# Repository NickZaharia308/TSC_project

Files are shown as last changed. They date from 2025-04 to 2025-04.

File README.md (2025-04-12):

# Nicusor-Alexandru Zaharia 335CA – Open-Source E-Book Reader

## Description
**OpenBook** is a fully open-source, ESP32-C6-powered e-book reader designed to be affordable, customizable, and easy to manufacture. It features a crisp e-paper display, modular hardware, and full documentation – empowering developers and hardware enthusiasts to build their own e-reader from scratch.

The project contains the **Product Design** with a complete [`schematic`](Hardware/Schematic.sch), [`PCB`](Hardware/PCB_2D.brd) and [`3D Model`](Mechanical/Completed%203D%20model%20v1.f3z).

---

## Repository Hierarchy

- Hardware
  ├── Schematic file (.sch)  
  └── Board layout file (.brd)  

- Manufacturing
  ├── Gerber files archive (gerbers.zip)  
  ├── Bill of Materials file (.bom)  
  └── Pick and Place file (.cpl)  

- Mechanical
  ├── 3D model of the complete device (PCB + battery + display + case) – exploded view (.step)  
  └── Fusion 360 project file of the complete device  

- Images
  └── Renders of the device

- LICENSE  
- README.md  

---

##  E-Book Reader Block Diagram
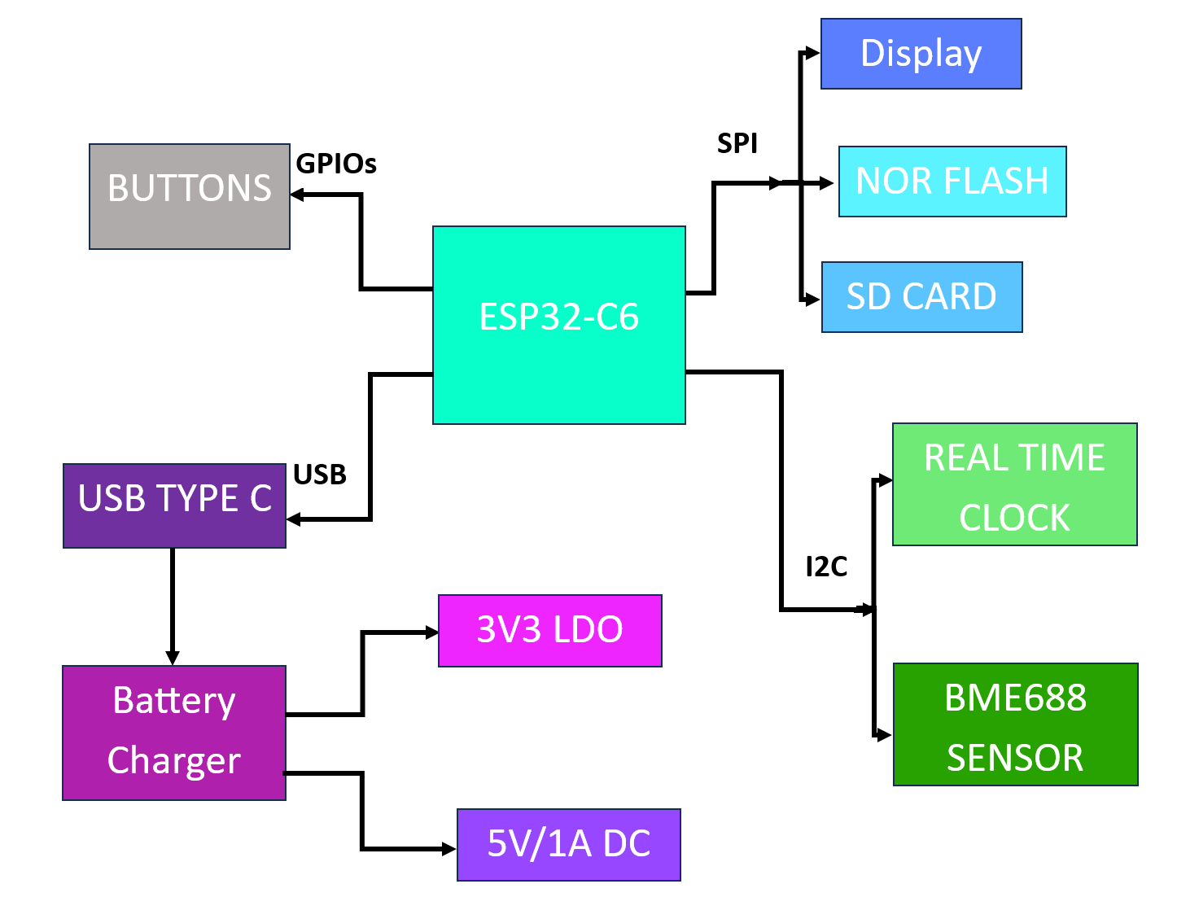
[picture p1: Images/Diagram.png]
E-book diagram


---

##   Design Process

1.  **Schematic Design:** The schematic was meticulously designed to align with the project's specified requirements. It highlights the important `components and modules`.
    
2.  **PCB Redesign:** The PCB layout was generated based on the size of the enclosure, and `components were strategically placed` according to design guidelines and best practices.
    
3.  **Routing Implementation:** Routing was used on both the top and bottom layers of the PCB. `Signal traces` were set to a width of 0.15mm while `the power traces` were organized into a dedicated net class named `Power class` routed with a width of 0.3mm to ensure optimal power distribution.
    
4.  **Ground Plane and Via Stitching:** `Ground planes` were implemented on both the top and bottom layers. `Via stitching` was applied, particularly in proximity to the ESP module, to establish effective interlayer connections and minimize ground impedance. `Vias` were used to interconnect the ground planes.
    
5.  **3D Model Integration:** `3D models` of the components were found with the link to them at the bottom of the README, integrated into Fusion 360, and accurately placed on the `PCB layout` to facilitate mechanical design and visualization.
    
6.  **Enclosure Integration:** The PCB was integrated into its intended enclosure. The enclosure design was adapted to accommodate buttons, connectors, and other external interface elements. `Battery` and `display` 3D models were developed positioned within the enclosure to ensure proper fit and alignment.

7.  **Export and Manufacturing Preparation:** The final stage involved `generating all necessary manufacturing` documentation, including Gerber files, Pick and Place (CPL) data, and the Bill of Materials (BOM), to prepare the design for fabrication and assembly.

---

## Decision Making

I switched the original [battery](https://www.tme.eu/Document/e0683d8c34e6d878124489f71bffb6ee/cel0014.pdf) from cellevia batteries with a similar [one](https://www.elektronik.ropla.eu/pdf/stock/aky/aky0099.pdf) (same electrical parameters) from akyga with a size that enters well in the enclosure and beside that it also has a lifecycle of `500 charges` as opossed to only `300 charges`

---

## Component Description and Interaction

### Microcontroller

* **ESP32-C6-WROOM-1-NI (U2):** This is the core of the board, a powerful microcontroller with Wi-Fi and Bluetooth Low Energy (BLE) connectivity. It is responsible for controlling all other components, processing data, and external communication.

### Power Supply

* **Li-Po Battery Charging Controller (MCP73831):** This circuit enables the board to be powered from a Li-Po battery and manages the charging process when an external power source is connected via the USB-C connector.
* **USB C connector:** Provides the interface for powering the board and potentially for data transfer. Includes `ESD (Electrostatic Discharge) protection`.
* **LDO Voltage Regulator (XC8220A331MR-G):** An LDO (Low Dropout) voltage regulator is used to provide a `stable 3.3V voltage` required for powering most of the components on the board, derived from the battery voltage or USB.
* **Supercapacitor (CPH3225A):** A supercapacitor is present, possibly to provide a backup power source for certain critical functions, such as the RTC module, in case the main power supply is interrupted.
* **Reverse Polarity Protection (MBR0530):** Schottky diodes are used to protect the circuits against incorrect polarity connection of the power source.
* **Capacitors (electrolytic, tantalum, ceramic):** Various types and values of capacitors are used for `power supply filtering, decoupling, and temporary energy storage` at different points in the circuit.

### Display

* **E-Paper Display Header (FH34SR-24S-0.5SH):** A header connector is provided for connecting an `E-Paper display`. This type of display is known for its low power consumption and image retention without power.
* **Display Type Selector:** A set of pull-up/pull-down resistors connected to ESP32-C6 pins allows for the detection of the connected E-Paper display type.

### Sensors

* **Environmental Sensor BME688:** This sensor integrates `temperature, humidity, atmospheric pressure, and air quality` (VOC - volatile organic compounds) measurement functions. It communicates with the ESP32-C6 via the `I2C` interface.
* **RTC Module DS3231SN:** A Real-Time Clock (RTC) module that maintains accurate time and date information, even when the board is powered off, being powered by the supercapacitor or a small battery. It communicates with the ESP32-C6 via `the I2C interface`.
* **Battery Charge Level (MAX17048G+T10):** A dedicated integrated circuit for monitoring the charge level of the Li-Po battery. It communicates with the ESP32-C6 via the `I2C interface`.

### User Interaction

* **Boot/IO Button (BOOT BUTTON):** A button used to force the ESP32-C6 into bootloader mode for programming or to perform an application-specific function.
* **Reset Button (RESET BUTTON):** A button to reset the ESP32-C6 microcontroller.
* **Change Button (CHANGE):** A button with an application-defined functionality, for navigation or selection.
* **CHG LED:** An LED indicator for the battery charging status.

### External Memory

* **External NOR Flash 64MB (W25Q512JVEIQ):** An external `64MB SPI flash memory`, used for storing firmware, data, or additional resources required by the application, exceeding the ESP32-C6's internal flash memory capacity. Good to keep `more books to read`.

### Connectivity and Interfaces

* **USB C connector:** For power and potential data transfer.
* **E-Paper Display Header:** Dedicated connector for the E-Paper display.
* **Qwiic/Stemma QT Connector:** A standard `I2C connector that allows for easy connection of additional I2C-compatible sensors or actuators`.
* **SPI ESD Protection Lines:** ESD protection circuits for the SPI communication lines, used for the external flash memory interface.
* **Test Pads (TP1-TP17):** Test points distributed across the board to facilitate debugging and `signal verification`.

### Miscellaneous

* **GND:** Multiple ground points for ensuring a stable voltage reference.
* **Resistors:** Various resistors are used for `pull-up, pull-down, current limiting, and voltage division`.
* **Diodes:** Diodes with various purposes, such as `protection or rectification`.
* **Inductor:** An inductor, part of the `power supply circuit or for EMI filtering`.
* **MOSFETs:** MOSFET transistors used for power switching or other control functions.

##   ESP32-C6 Pin Usage

The following list details the ESP32-C6 pins used and the reason for their use:

* **Pin 10 (3V3):** Power supply pin for the ESP32-C6, connected to the 3.3V rail generated by the LDO.
* **Pin 8 (GHD):** A ground (GND) pin.
* **Pin 5 (GHD):** A ground (GND) pin.
* **Pin 20 (EN):** Enable pin for the ESP32-C6, controlled by a power management circuit or connected to a pull-up to keep it active.
* **Pin 21 (1011):** Connected to the BOOT button. It is configured as an input and used to initiate the ESP32-C6's bootloader mode at startup or reset. A pull-up resistor (R BOOT 10K) ensures a default high logic level, and pressing the button connects it to GND.
* **Pin 22 (1013):** Connected to the RESET button. Similar to the BOOT button, it's an input used to reset the microcontroller.
* **Pin 23 (1013):** Connected to the CHANGE button. It is configured as an input and used to detect user action. A pull-up resistor (10K) ensures a default high logic level, and pressing the button connects it to GND.
* **Pin 19 (102):** Connected to the SDA (Serial Data) line of the I2C bus. This line is used for bidirectional data communication with the BME688 sensor, the DS3231SN RTC module, and the MAX17048G battery monitoring circuit. Pull-up resistors will be present on the I2C bus.
* **Pin 18 (1015):** Connected to the SCL (Serial Clock) line of the I2C bus. This line provides the synchronization clock signal for I2C communication with the peripherals mentioned above. Similar to SDA, it requires pull-up resistors.
* **Pin 17 (132):** Connected to the CE (Chip Enable) pin of the external flash memory W25Q512JVEIQ. This pin is used to select the flash memory chip for SPI communication.
* **Pin 16 (10220):** Connected to the HOLD/RESET pin of the external flash memory. This pin has multiple functions related to controlling the write and read operations of the flash memory.
* **Pin 15 (10):** Connected to the WP (Write Protect) pin of the external flash memory. This pin is used to protect certain sectors of the flash memory against accidental writing.
* **Pin 14 (CE BAT):** Connected to the CE (Chip Enable) pin of the MAX17048G battery monitoring circuit. Used to enable communication with this circuit on the I2C bus.

**Pins Connected to E-Paper Display Header (FH34SR-24S-0.5SH):**

Several ESP32-C6 pins will be connected to the E-Paper display header to control and transmit data to it.

* Powering the display (via "EPD Power").
* Transmitting the data and control signals necessary for updating the image on the display. This could include pins for an SPI interface (data, clock, chip select) or another interface specific to the E-Paper display controller.

**Pins Connected to BME688 Sensor:**

* **SDA (connected to Pin 19 of ESP32-C6):** I2C data line.
* **SCL (connected to Pin 18 of ESP32-C6):** I2C clock line.
* **VDDIO:** Power supply pin for the sensor's logic interface, connected to 3.3V.
* **VDD:** Power supply pin for the sensor, connected to 3.3V.
* **CSH:** Chip Select pin for the SPI interface.
* **SCK:** Serial Clock pin for the SPI interface.
* **SDO:** Serial Data Out pin for the SPI interface.

**Pins Connected to DS3231SN RTC Module:**

* **SDA (connected to Pin 19 of ESP32-C6):** I2C data line.
* **SCL (connected to Pin 18 of ESP32-C6):** I2C clock line.
* **VCC:** Power supply pin, connected to 3.3V or the supercapacitor voltage to maintain RTC operation.
* **SQW/INT# (ALERT):** An output pin that can be configured as a square wave output or an alarm/interrupt output, connected to a GPIO pin of the ESP32-C6.

**Pins Connected to MAX17048G Battery Charge Level Circuit:**

* **SDA (connected to Pin 19 of ESP32-C6):** I2C data line.
* **SCL (connected to Pin 18 of ESP32-C6):** I2C clock line.
* **CE (connected to Pin 14 of ESP32-C6):** Chip Enable pin for selecting the I2C circuit.
* **ALERT:** An alert output pin that can indicate low battery level or other events, connected to a GPIO pin of the ESP32-C6.

**Pins Connected to W25Q512JVEIQ (U1) External Flash Memory:**

* **CS# (Chip Select):** Connected to Pin 17 of ESP32-C6.
* **CLK (Serial Clock):** An ESP32-C6 SPI CLK pin.
* **MOSI (Master Out Slave In):** An ESP32-C6 SPI MOSI pin.
* **MISO (Master In Slave Out):** An ESP32-C6 SPI MISO pin.
* **HOLD/RESET#:** Connected to Pin 16 of ESP32-C6.
* **WP# (Write Protect):** Connected to Pin 15 of ESP32-C6.

**Pins Connected to Qwiic/Stemma QT Connector:**

* **SDA:** Connected to Pin 19 of ESP32-C6.
* **SCL:** Connected to Pin 18 of ESP32-C6.
* **VCC (3V3):** Power supply for connected devices.
* **GND:** Ground.

---

## Images

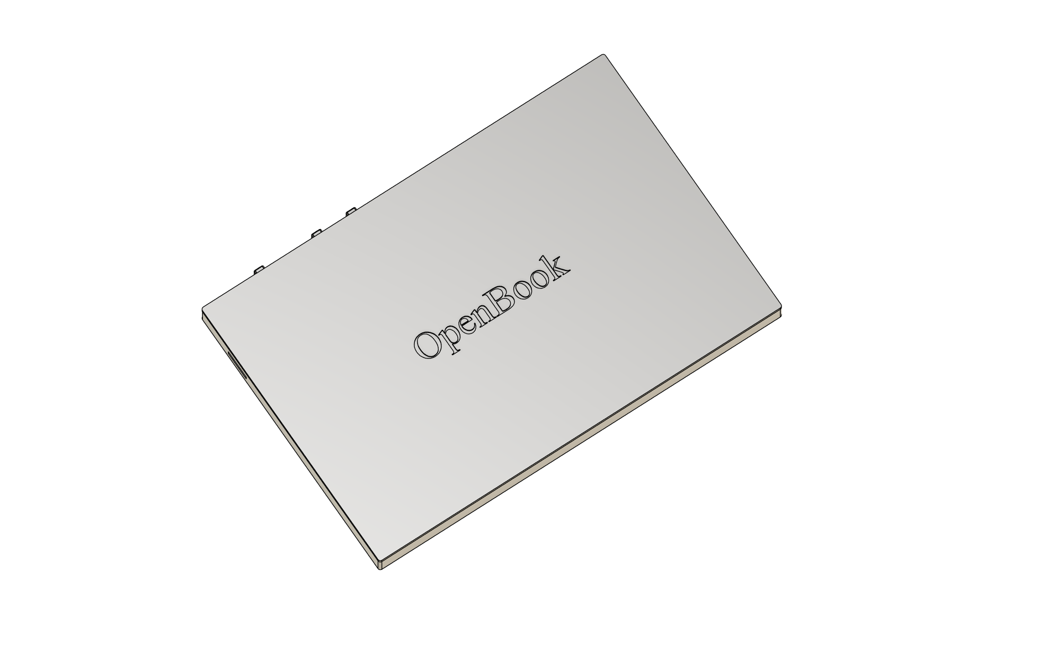
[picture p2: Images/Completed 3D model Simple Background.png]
Product
  
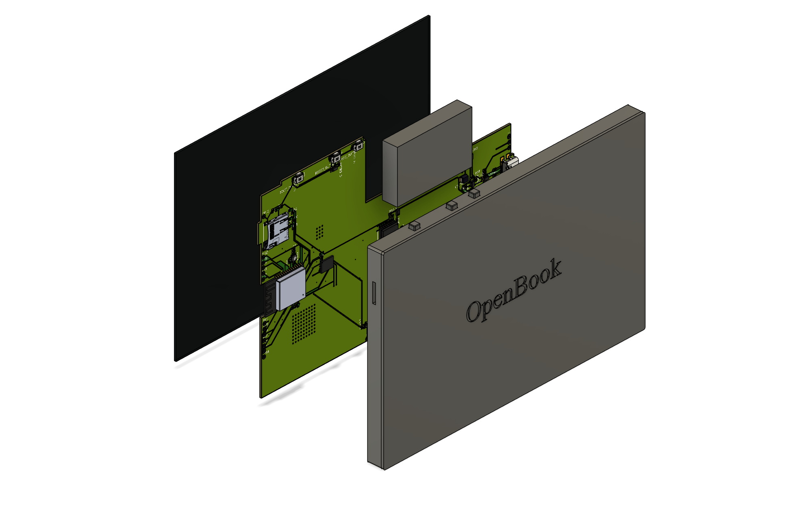
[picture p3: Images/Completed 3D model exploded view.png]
Exploded view

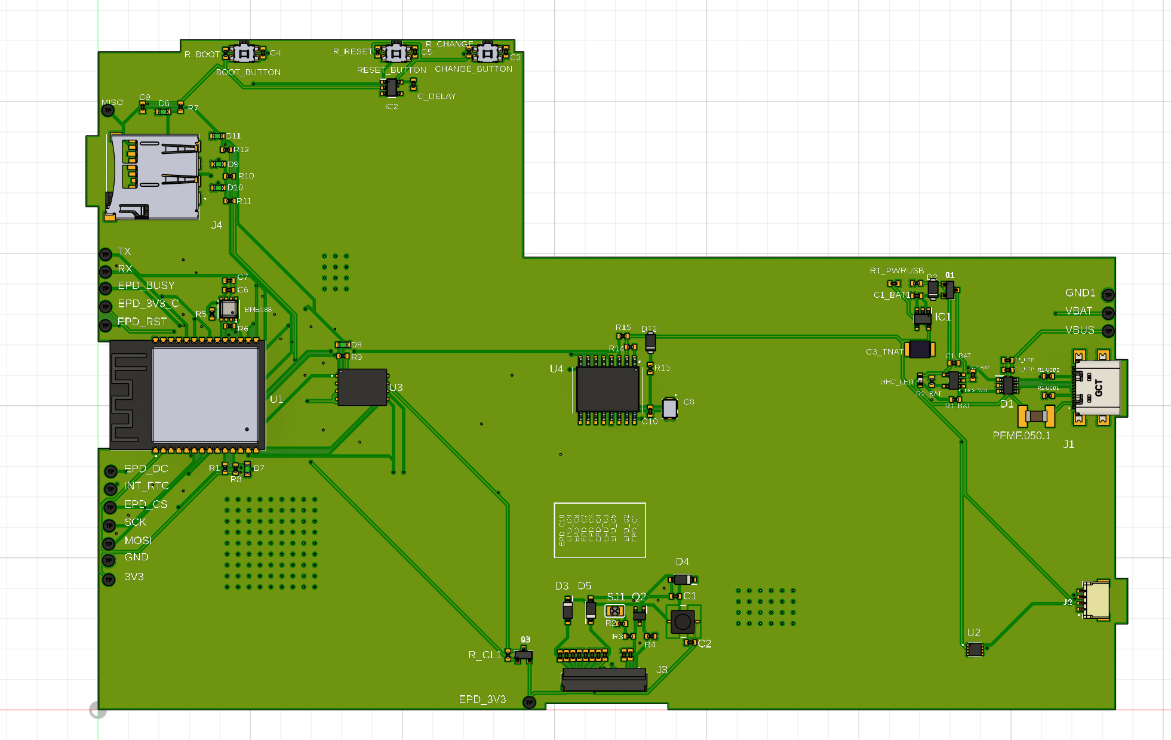
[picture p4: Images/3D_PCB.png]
3D_PCB


---

## Bill of Materials

| Component | Product Link | Datasheet |
|---|---|---|
| ESP32-C6 WROOM-1-N8 | [SnapMagic](https://www.snapeda.com/parts/ESP32-C6-WROOM-1-N8/Espressif+Systems/view-part/?ref=eda) | [Datasheet](https://www.snapeda.com/parts/ESP32-C6-WROOM-1-N8/Espressif%20Systems/datasheet/) |
| ESP32C6 Varistor 1812 | [Mouser](https://ro.mouser.com/ProductDetail/EPCOS-TDK/B72520T0350K062?qs=dEfas%2FXlABIszF52uu7vrg%3D%3D) | [Datasheet](https://www.tdk-electronics.tdk.com/inf/75/db/CTVS_14/Surge_protection_series.pdf) |
| ESP32 WROVER 0805 Capacitor | [Mouser](https://ro.mouser.com/ProductDetail/KYOCERA-AVX/SD0805S020S1R0?qs=jCA%252BPfw4LHbpkAoSnwrdjw%3D%3D) | [Datasheet](https://ro.mouser.com/datasheet/2/40/schottky-3165252.pdf) |
| ESP32 WROVER BME680 Sensor | [SnapMagic](https://www.snapeda.com/parts/BME680/Bosch/view-part/?welcome=home) | [Datasheet](https://www.snapeda.com/parts/BME680/Bosch%20Sensortec/datasheet/) |
| ESP32 WROVER MCP73831 Power Management | [Mouser](https://eu.mouser.com/ProductDetail/Microchip-Technology/MCP73831T-2ACI-OT?qs=yUQqVecv4qvbBQBGbHx0Mw%3D%3D) | [Datasheet](https://eu.mouser.com/datasheet/2/268/MCP73831_Family_Data_Sheet_DS20001984H-3441711.pdf) || ESP32 WROVER P-Channel MOSFET | [Component Search Engine](https://componentsearchengine.com/part-view/DMG2305UX-7/Diodes%20Incorporated) | [Datasheet](https://www.diodes.com//assets/Datasheets/DMG2305UX.pdf) |
| LED Chip 0603 | [SnapMagic](https://www.snapeda.com/parts/KP-1608SURCK/Kingbright/view-part/?ref=search&t=LED%200603) | [Datasheet](https://www.snapeda.com/parts/KP-1608SURCK/Kingbright/datasheet/) |
| SJ | [GrabCad](https://grabcad.com/library/solder-jumpers-1) | [Datasheet](https://en.wikipedia.org/wiki/HTTP_404) |
| LTSPICE Resistor 0402 | [Component Search Engine](https://componentsearchengine.com/part-view/R0402%201%25%20100%20K%20(RC0402FR-07100KL)/YAGEO) | [Datasheet](https://www.yageo.com/upload/media/product/products/datasheet/rchip/PYu-RC_Group_51_RoHS_L_12.pdf) |
| RCL CPOL 3528 | [SnapMagic](https://www.snapeda.com/parts/TAJB475K025RNJ/AVX/view-part/?ref=dk&t=capacitor%203528&con_ref=None) | [Datasheet](https://s3.amazonaws.com/snapeda/datasheet/TAJB475K025RNJ_AVX.pdf) |
| 112A-TAAR-R03 | [Comet](https://store.comet.srl.ro/Catalogue/Product/43497/) | [Datasheet](https://store.comet.bg/download-file.php?id=27596) |
| Capacitor 0402 | [Component Search Engine](https://componentsearchengine.com/part-view/CC0402MRX5R5BB106/YAGEO) | [Datasheet](https://componentsearchengine.com/Datasheets/2/CC0402MRX5R5BB106.pdf) |
| 744043680 IND | [Mouser](https://eu.mouser.com/ProductDetail/Wurth-Elektronik/744043680?qs=PGXP4M47uW6VkZq%252BkzjrHA%3D%3D) | [Datasheet](https://www.we-online.com/components/products/datasheet/744043680.pdf) |
| BD5229G-TR | [Component Search Engine](https://componentsearchengine.com/part-view/BD5229G-TR/ROHM%20Semiconductor) | [Datasheet](https://datasheet.datasheetarchive.com/originals/distributors/Datasheets_SAMA/f2b9741ef86007909f138d561a359946.pdf) |
| Custom Button | [Panasonic](https://industry.panasonic.com/global/en/products/control/switch/light-touch/number/evqpuj02k) | [Datasheet](https://industry.panasonic.com/global/en/downloads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) |
| CPH3225A | [SnapMagic](https://www.snapeda.com/parts/CPH3225A/Seiko+Instruments/view-part/?ref=eda) | [Datasheet](https://www.snapeda.com/parts/CPH3225A/Seiko%20Instruments/datasheet/) |
| DS3231SN RTC | [SnapMagic](https://www.snapeda.com/parts/DS3231SN%23/Analog+Devices/view-part/?ref=eda) | [Datasheet](https://www.snapeda.com/parts/DS3231SN%23/Analog%20Devices/datasheet/) |
| FH34SRJ-24S-0.5SH Connector | [Component Search Engine](https://componentsearchengine.com/part-view/FH34SRJ-24S-0.5SH(99)/Hirose) | [Datasheet](https://www.hirose.com/en/product/document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) |
| MAX17048G+T10 Battery Fuel Gauge | [SnapMagic](https://www.snapeda.com/parts/MAX17048G+T10/Analog+Devices/view-part/?ref=eda) | [Datasheet](https://www.snapeda.com/parts/MAX17048G+T10/Analog%20Devices/datasheet/) |
| MBR0530 Schottky Diode | [SnapMagic](https://www.snapeda.com/parts/MBR0530/Onsemi/view-part/?ref=eda) | [Datasheet](https://www.snapeda.com/parts/MBR0530/ON%20Semiconductor/datasheet/) |
| PGB1010603MR Inductor | [SnapMagic](https://www.snapeda.com/parts/PGB1010603MR/Littelfuse/view-part/?ref=eda) | [Datasheet](https://www.snapeda.com/parts/PGB1010603MR/Littelfuse%20Inc./datasheet/) |
| QWIIC Connector | [Mouser](https://eu.mouser.com/ProductDetail/Adafruit/4208?qs=PzGy0jfpSMtbScLbr0L5dw%3D%3D) | [Datasheet](https://en.wikipedia.org/wiki/HTTP_404) |
| USB4110-GF-A USB Hub | [Component Search Engine](https://componentsearchengine.com/part-view/USB4110-GF-A/GCT%20(GLOBAL%20CONNECTOR%20TECHNOLOGY)) | [Datasheet](https://gct.co/files/drawings/usb4110.pdf) |
| SI1308EDL-T1-GE3 MOSFET | [SnapMagic](https://www.snapeda.com/parts/SI1308EDL-T1-GE3/Vishay+Siliconix/view-part/?ref=eda) | [Datasheet](https://en.wikipedia.org/wiki/HTTP_404) |
| TPTP20R | [Comet](https://easyeda.com/component/7524403feb2642ac9f9f26dfb93ceacf) | [Datasheet](https://easyeda.com/component/7524403feb2642ac9f9f26dfb93ceacf) |
| USBLC6-2SC6Y USB Surge Protection | [SnapMagic](https://www.snapeda.com/parts/USBLC6-2SC6Y/STMicroelectronics/view-part/?ref=eda) | [Datasheet](https://www.snapeda.com/parts/USBLC6-2SC6Y/STMicroelectronics/datasheet/) |
| W25Q512JVEIQ Flash Memory | [SnapMagic](https://www.snapeda.com/parts/W25Q512JVEIQ/Winbond+Electronics/view-part/?ref=eda) | [Datasheet](https://www.snapeda.com/parts/W25Q512JVEIQ/Winbond%20Electronics/datasheet/) |
| XC6220A331MR-G Voltage Regulator | [Component Search Engine](https://componentsearchengine.com/part-view/XC6220A331MR-G/Torex) | [Datasheet](https://product.torexsemi.com/system/files/series/xc6220.pdf) |

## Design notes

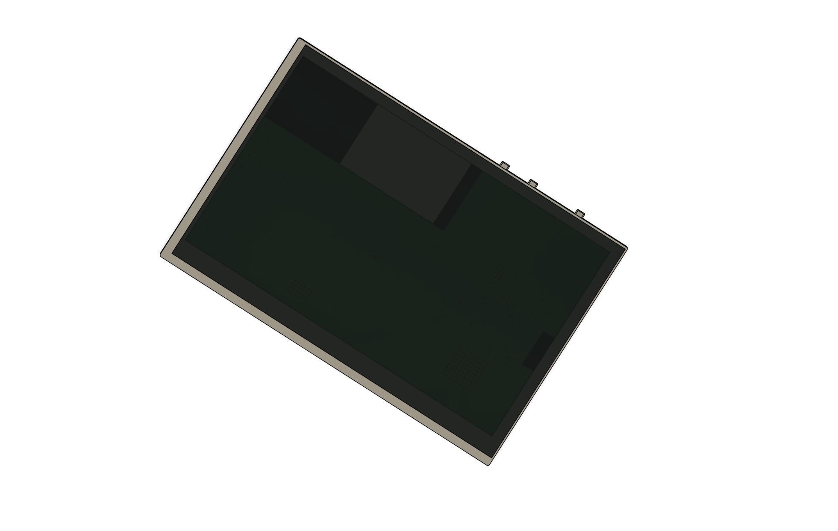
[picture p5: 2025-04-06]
Images/Completed 3D model Transparent Display.png

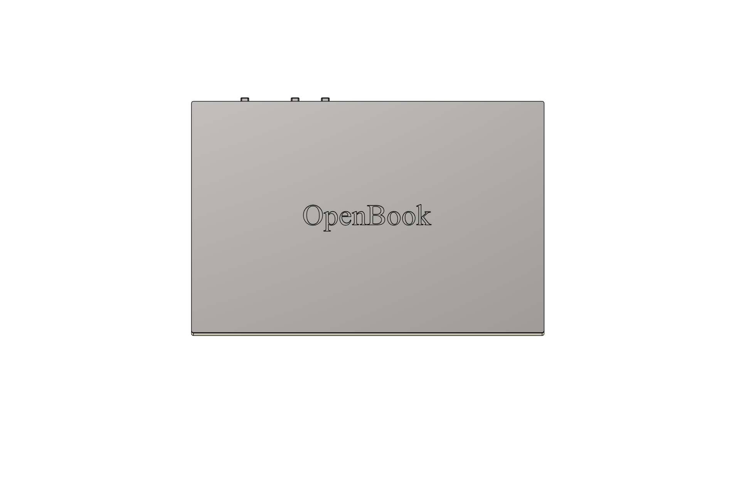
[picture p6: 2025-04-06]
Images/Completed 3D model Top Model.png

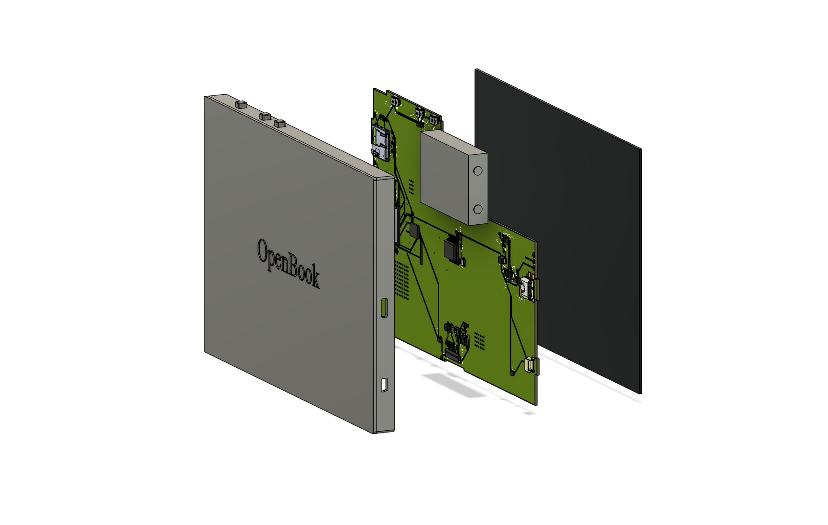
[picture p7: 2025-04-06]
Images/Completed 3D model exploded view 2.png

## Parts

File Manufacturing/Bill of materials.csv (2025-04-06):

Qty | Value | Device | Package | Parts | Description | ARROW_PART_NUMBER | ARROW_PRICE-STOCK | AVAILABILITY | CENTROID_NOT_SPECIFIED | CHECK_PRICES | COPYRIGHT | DATASHEET | DESCRIPTION | DIGIKEY_DESCRIPTION | DIGIKEY_PART_NUMBER | HEIGHT | LEAD_FREE | MANUFACTURER_NAME | MANUFACTURER_PART_NUMBER | MF | MFR_NAME | MOUSER_PART_NUMBER | MOUSER_PRICE-STOCK | MP | MPN | PACKAGE | POPULARITY | PREFIX | PRICE | PROD_ID | PURCHASE-URL | ROHS | SNAPEDA_LINK | SPICEMODEL | SPICEPREFIX | TEMPERATURE_RANGE_HIGH | TEMPERATURE_RANGE_LOW | TP_SIGNAL_NAME | VALUE
1 |  | ADAFRUIT_LEDCHIP-LED0603 | ADAFRUIT_CHIP-LED0603 | GHC_LED | LED
1 |  | SJ | SJ | SJ1 | SMD solder JUMPER |  |  |  |  |  |  |  |  |  |  |  |  |  |  |  |  |  |  |  |  |  | 3
1 | 0.1uF/50V | EAGLE-LTSPICE_CC0402 | EAGLE-LTSPICE_C0402 | EPD_C5 | CAPACITOR, European symbol |  |  |  |  |  |  |  |  |  |  |  |  |  |  |  |  |  |  |  |  |  |  |  |  |  |  |  |  | NONE | C
1 | 0.47 | ESP32_WROVER_EAGLE-LTSPICE_R | ESP32_WROVER_EAGLE-LTSPICE_R0402 | R3 | RESISTOR, European symbol
1 | 100K | ESP32_WROVER_EAGLE-LTSPICE_R | ESP32_WROVER_EAGLE-LTSPICE_R0402 | R1_PWRUSB | RESISTOR, European symbol
8 | 100nF | EAGLE-LTSPICE_CC0402 | EAGLE-LTSPICE_C0402 | C3, C4, C4_USB, C6, C7, C9, C10, C_DELAY | CAPACITOR, European symbol |  |  |  |  |  |  |  |  |  |  |  |  |  |  |  |  |  |  |  |  |  |  |  |  |  |  |  |  | NONE | C
1 | 100uF | RCL_CPOL-EUCT3528 | RCL_CT3528 | C3_TNAT | POLARIZED CAPACITOR, European symbol |  |  |  |  |  |  |  |  |  |  |  |  |  |  |  |  |  |  |  |  |  | 0 |  |  |  |  |  |  |  | C
16 | 10K | ESP32_WROVER_EAGLE-LTSPICE_R | ESP32_WROVER_EAGLE-LTSPICE_R0402 | R1, R4, R5, R6, R7, R8, R9, R10, R11, R12, R14, R15, R_BOOT, R_CHANGE, R_CL1, R_RESET | RESISTOR, European symbol
1 | 10uF | EAGLE-LTSPICE_CC0402 | EAGLE-LTSPICE_C0402 | C2 | CAPACITOR, European symbol |  |  |  |  |  |  |  |  |  |  |  |  |  |  |  |  |  |  |  |  |  |  |  |  |  |  |  |  | NONE | C
1 | 112A-TAAR-R03_ATTENDPACHET | 112A-TAAR-R03_ATTENDPACHET | 112ATAARR03ATTEND | J4 | Micro SD Card Socket, Push-Push Type, Top Mount, SMT, H=1.83mm, 10u
1 | 15 | ESP32_WROVER_EAGLE-LTSPICE_R | ESP32_WROVER_EAGLE-LTSPICE_R0402 | R13 | RESISTOR, European symbol
1 | 1uF | EAGLE-LTSPICE_CC0402 | EAGLE-LTSPICE_C0402 | C5 | CAPACITOR, European symbol |  |  |  |  |  |  |  |  |  |  |  |  |  |  |  |  |  |  |  |  |  |  |  |  |  |  |  |  | NONE | C
9 | 1uF/50V | EAGLE-LTSPICE_CC0402 | EAGLE-LTSPICE_C0402 | EPD_C1, EPD_C2, EPD_C3, EPD_C4, EPD_C6, EPD_C7, EPD_C8, EPD_C9, EPD_C10 | CAPACITOR, European symbol |  |  |  |  |  |  |  |  |  |  |  |  |  |  |  |  |  |  |  |  |  |  |  |  |  |  |  |  | NONE | C
1 | 2.2 | ESP32_WROVER_EAGLE-LTSPICE_R | ESP32_WROVER_EAGLE-LTSPICE_R0402 | R2 | RESISTOR, European symbol
1 | 200 | ESP32_WROVER_EAGLE-LTSPICE_R | ESP32_WROVER_EAGLE-LTSPICE_R0402 | R1_BAT | RESISTOR, European symbol
2 | 20V/4.2A/52mO/1.4W | ESP32_WROVER_SPARKFUN-DISCRETESEMI_MOSFET_PCH-DMG2305UX-7 | ESP32_WROVER_SPARKFUN-DISCRETESEMI_SOT23-3 | Q1, Q3 | P-channel MOSFETs |  |  |  |  |  |  |  |  |  |  |  |  |  |  |  |  |  |  |  |  |  |  |  |  | TRAN-14388 |  |  |  |  |  |  |  |  | 20V/4.2A/52mO/1.4W
1 | 2K | ESP32_WROVER_EAGLE-LTSPICE_R | ESP32_WROVER_EAGLE-LTSPICE_R0402 | R2_BAT | RESISTOR, European symbol
5 | 4.7uF | EAGLE-LTSPICE_CC0402 | EAGLE-LTSPICE_C0402 | C1_BAT, C1_BAT1, C1_BAT2, C2_BAT, C5_USB | CAPACITOR, European symbol |  |  |  |  |  |  |  |  |  |  |  |  |  |  |  |  |  |  |  |  |  |  |  |  |  |  |  |  | NONE | C
1 | 4.7uF/25V | EAGLE-LTSPICE_CC0402 | EAGLE-LTSPICE_C0402 | C1 | CAPACITOR, European symbol |  |  |  |  |  |  |  |  |  |  |  |  |  |  |  |  |  |  |  |  |  |  |  |  |  |  |  |  | NONE | C
2 | 5K1 | ESP32_WROVER_EAGLE-LTSPICE_R | ESP32_WROVER_EAGLE-LTSPICE_R0402 | R2-USB1, R2-USB2 | RESISTOR, European symbol
1 | 68uH | 744043680IND_4828-WE-TPC_WRE | IND_4828-WE-TPC_WRE | L1 |  |  |  |  |  |  | Copyright (C) 2024 Ultra Librarian. All rights reserved. |  |  |  |  |  |  |  | 744043680 |  | Wurth Electronics
1 | BD5229G-TR | BD5229G-TR | SOT95P280X125-5N | IC2 | Voltage Detector with Adjustable Delay Time: CMOS processes are utilized to develop high precision, low current consumption CMOS reset ICs that allow arbitrary setting of the delay time. The extensive lineup includes both Nch Open Drain and CMOS output types in a wide range of detection voltages (from 2.3V to 6.0V, in 0.1V steps), enabling selection of the ideal solution based on customer requirements. In addition, the entire series is of course both lead-free and RoHS-compliant. |  |  |  |  |  |  |  | Voltage Detector with Adjustable Delay Time: CMOS processes are utilized to develop high precision | low current consumption CMOS reset ICs that allow arbitrary setting of the delay time. The extensive lineup includes both Nch Open Drain and CMOS output types in a wide range of detection voltages (from 2.3V to 6.0V | in 0.1V steps) | enabling selection of the ideal solution based on customer requirements. In addition | the entire series is of course both lead-free and RoHS-compliant. |  |  | 1.25mm |  | ROHM Semiconductor | BD5229G-TR |  |  | 755-BD5229G-TR | https://www.mouser.co.uk/ProductDetail/ROHM-Semiconductor/BD5229G-TR?qs=4kLU8WoGk0vvnhrrYwdszw%3D%3D
3 | BUTTON_CUSYOMV1 | BUTTON_CUSYOMV1MINE | MYBUTTON | BOOT_BUTTON, CHANGE_BUTTON, RESET_BUTTON
1 | CPH3225A | CPH3225A | CAPCP3225X100N | C8 | Cap 0.011F 3.3V 1210 Flat Check availability |  |  | Not in stock |  | https://www.snapeda.com/parts/CPH3225A/Seiko+Instruments/view-part/?ref=eda |  |  | 11 mF (EDLC) Supercapacitor 3.3 V 1210 (3225 Metric) - - |  |  |  |  |  |  | Seiko Instruments |  |  |  | CPH3225A |  | 1210 Seiko |  |  | None |  | https://www.snapeda.com/api/url_track_click_mouser/?unipart_id=562593&manufacturer=Seiko Instruments&part_name=CPH3225A&search_term=None |  | https://www.snapeda.com/parts/CPH3225A/Seiko+Instruments/view-part/?ref=snap
1 | DS3231SN# | DS3231SN# | SOIC127P1032X265-16N | U4 | Real Time Clock Serial 16-Pin SOIC W T/R Check availability |  |  | In Stock |  | https://www.snapeda.com/parts/DS3231SN%23/Analog+Devices/view-part/?ref=eda |  |  | Extremely Accurate I²C-Integrated RTC/TCXO/Crystal |  |  |  |  |  |  | Analog Devices |  |  |  | DS3231SN# |  | SOIC-16 Maxim |  |  | None |  | https://www.snapeda.com/api/url_track_click_mouser/?unipart_id=99048&manufacturer=Analog Devices&part_name=DS3231SN#&search_term=None |  | https://www.snapeda.com/parts/DS3231SN%23/Analog+Devices/view-part/?ref=snap
1 | ESP32-C6-WROOM-1-N8 | ESP32-C6-WROOM-1-N8 | XCVR_ESP32-C6-WROOM-1-N8 | U1 | Check availability |  |  | In Stock |  | https://www.snapeda.com/parts/ESP32-C6-WROOM-1-N8/Espressif+Systems/view-part/?ref=eda |  |  | Multiprotocol Modules ESP32-C6 module | Wi-Fi 6 in 2.4 GHz band | Bluetooth 5 | Zigbee 3.0 and Thread. ESP34-WROOM Compatible - ENGINEERING SAMPLE |  |  |  |  |  |  | Espressif Systems |  |  |  | ESP32-C6-WROOM-1-N8 |  | None |  |  | None |  |  |  | https://www.snapeda.com/parts/ESP32-C6-WROOM-1-N8/Espressif+Systems/view-part/?ref=snap
1 | ESP32C6_VARISTORCN1812 | ESP32C6_VARISTORCN1812 | ESP32C6_VARISTOR_CT/CN1812 | PFMF.050.1 | VARISTOR |  |  |  |  |  |  |  |  |  |  |  |  |  |  |  |  |  |  |  |  |  | 0
2 | ESP32_WROVER_AVX---SD0805S020S1R0_AVX_SD0805S020S1R0_0_0AVX_SD0805S020S1R0_0_0 | ESP32_WROVER_AVX---SD0805S020S1R0_AVX_SD0805S020S1R0_0_0AVX_SD0805S020S1R0_0_0 | ESP32_WROVER_AVX---SD0805S020S1R0_AVX_SD0805S020S1R0_0 | D2, D12 | Schottky Barrier Rectifier Diode |  |  |  | No |  |  | http://datasheets.avx.com/schottky.pdf |  | DIODE SCHOTTKY 20V 1A 0805 | 478-7800-1-ND |  | yes |  |  | AVX |  | 581-SD0805S020S1R0 |  |  |  | 0805 (2012 metric) |  | D |  |  |  | yes |  |  |  | +125°C | -55°C
1 | ESP32_WROVER_BME680_BME680 | ESP32_WROVER_BME680_BME680 | ESP32_WROVER_BME680_PSON80P300X300X100-8N | BME688 | Integrated Environmental Unit |  |  | Unavailable |  |  |  |  | Integrated Environmental Unit |  |  |  |  |  |  | Bosch Sensortec |  |  |  | BME680 |  | LGA-8 Bosch Tools |  |  | None
1 | ESP32_WROVER_SPARKFUN-IC-POWER_MCP73831 | ESP32_WROVER_SPARKFUN-IC-POWER_MCP73831 | ESP32_WROVER_SPARKFUN-IC-POWER_SOT23-5 | MCP73831 | MCP73831T Li-Ion, Li-Pol Controller |  |  |  |  |  |  |  |  |  |  |  |  |  |  |  |  |  |  |  |  |  |  |  |  | IC-09995
1 | FH34SRJ-24S-0.5SH_99_ | FH34SRJ-24S-0.5SH_99_ | FH34SRJ24S05SH99 | J3 | (0.50mm) Surface Mount, Right Angle |  |  |  |  |  |  |  | 24 Position FFC | FPC Connector Contacts | (0.50mm) Surface Mount | Right Angle |  |  | 1.1mm |  | Hirose | FH34SRJ-24S-0.5SH(99) |  |  | 798-FH34SRJ24S05SH99 | https://www.mouser.co.uk/ProductDetail/Hirose-Connector/FH34SRJ-24S-0.5SH99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
1 | MAX17048G+T10 | MAX17048G+T10 | SON50P200X200X80-9N | U2 | Check availability |  |  | In Stock |  | https://www.snapeda.com/parts/MAX17048G+T10/Analog+Devices/view-part/?ref=eda |  |  | 3µA 1-Cell/2-Cell Fuel Gauge with ModelGauge |  |  |  |  |  |  | Analog Devices |  |  |  | MAX17048G+T10 |  | TDFN-8 Maxim |  |  | None |  | https://www.snapeda.com/api/url_track_click_mouser/?unipart_id=329239&manufacturer=Analog Devices&part_name=MAX17048G+T10&search_term=None |  | https://www.snapeda.com/parts/MAX17048G+T10/Analog+Devices/view-part/?ref=snap
3 |  |  | SOD3716X135N | D3, D4, D5 | ON SEMICONDUCTOR - MBR0530 - DIODE, SCHOTTKY, 0.5A, 30V, SOD-123
6 |  |  | DIOC1608X36N | D6, D7, D8, D9, D10, D11 | Check availability
1 | QWIIC_RIGHT_ANGLE | QWIIC_CONNECTORJS-1MM | JST04_1MM_RA | J2 | SparkFun I2C Standard Qwiic Connector |  |  |  |  |  |  |  |  |  |  |  |  |  |  |  |  |  |  |  |  |  |  |  |  | CONN-13694 |  |  |  |  |  |  |  |  | QWIIC_RIGHT_ANGLE
1 | SAMACSYS_PARTS_USB4110-GF-A | SAMACSYS_PARTS_USB4110-GF-A | SAMACSYS_PARTS_USB4110GFA | J1 | CONN USB 2.0 TYPE-C R/A SMT |  |  |  |  |  |  |  | CONN USB 2.0 TYPE-C R/A SMT |  |  | 3.26mm |  | GCT (GLOBAL CONNECTOR TECHNOLOGY) | USB4110-GF-A |  |  | 640-USB4110-GF-A | https://www.mouser.co.uk/ProductDetail/GCT/USB4110-GF-A?qs=KUoIvG%2F9IlYiZvIXQjyJeA%3D%3D
1 | SI1308EDL-T1-GE3 | SI1308EDL-T1-GE3 | SOT65P210X110-3N | Q2 | MOSFET N-Ch 30V 1.5A TrenchFET SC70 Vishay Si1308EDL-T1-GE3 N-channel MOSFET Transistor, 1.5 A, 30 V, 3-Pin SC-70 |  |  | In Stock |  | https://www.snapeda.com/parts/SI1308EDL-T1-GE3/Vishay+Siliconix/view-part/?ref=eda |  |  | Si1308EDL-T1-GE3 N-channel MOSFET Transistor | 1.5 A | 30 V | 3-Pin SC-70 | Siliconix / Vishay SI1308EDL-T1-GE3 |  |  |  |  |  |  | Vishay Siliconix |  |  |  | SI1308EDL-T1-GE3 |  | SOT-323 Vishay Semiconductor |  |  | None |  | https://www.snapeda.com/api/url_track_click_mouser/?unipart_id=274603&manufacturer=Vishay Siliconix&part_name=SI1308EDL-T1-GE3&search_term=None |  | https://www.snapeda.com/parts/SI1308EDL-T1-GE3/Vishay+Siliconix/view-part/?ref=snap
17 | TPTP20R | TPTP20R | TP20R | TP1, TP2, TP3, TP4, TP5, TP6, TP7, TP8, TP9, TP10, TP11, TP12, TP13, TP14, TP15, TP16, TP17 | Test pad |  |  |  |  |  |  |  |  |  |  |  |  |  |  |  |  |  |  |  |  |  | 2
1 | USBLC6-2SC6Y | USBLC6-2SC6Y | SOT95P280X145-6N | D1 | Low Cap. ESD Protection Auto SOT-23-6 STMicroelectronics USBLC6-2SC6Y, Dual Uni-Directional TVS Diode Array, 6-Pin SOT-23 |  |  | In Stock |  | https://www.snapeda.com/parts/USBLC6-2SC6Y/STMicroelectronics/view-part/?ref=eda |  |  | 17V Clamp 5A (8/20µs) Ipp Tvs Diode Surface Mount SOT-23-6 |  |  |  |  |  |  | STMicroelectronics |  |  |  | USBLC6-2SC6Y |  | SOT-23-6 STMicroelectronics |  |  | None |  |  |  | https://www.snapeda.com/parts/USBLC6-2SC6Y/STMicroelectronics/view-part/?ref=snap
1 | W25Q512JVEIQ | W25Q512JVEIQ | SON127P600X800X80-9N | U3 | Check availability |  |  | In Stock |  | https://www.snapeda.com/parts/W25Q512JVEIQ/Winbond+Electronics/view-part/?ref=eda |  |  | FLASH - NOR Memory IC 512Mb (64M x 8) SPI - Quad I/O 133 MHz 8-WSON (8x6) |  |  |  |  |  |  | Winbond Electronics |  |  |  | W25Q512JVEIQ |  | Package |  |  | None |  |  |  | https://www.snapeda.com/parts/W25Q512JVEIQ/Winbond+Electronics/view-part/?ref=snap
1 | XC6220A331MR-G | XC6220A331MR-G | SOT95P280X120-5N | IC1 | LDO Voltage Regulators |  |  |  |  |  |  |  | LDO Voltage Regulators |  |  | 1.2mm |  | Torex | XC6220A331MR-G |  |  | 865-XC6220A331MR-G | https://www.mouser.co.uk/ProductDetail/Torex-Semiconductor/XC6220A331MR-G?qs=AsjdqWjXhJ8ZSWznL1J0gg%3D%3D

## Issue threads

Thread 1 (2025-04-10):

[3D Model] Modele 3D lipsa sau puse gresit

Matei-Dragusin, 2025-04-10:
# Descriere
Am observat unele modele 3D puse incorect pe placa.

# Probleme
Piesa nu face contact cu PCB-ul. [[1]](#poza1)
Piesa nu este aliniata corect pe pini. [[2]](#poza2) [[3]](#poza3)
Model 3D gresit (nu face contact deloc pe pini) [[4]](#poza4)
Model lipsa. [[5]](#poza5) [[6]](#poza6)
Modelul 3D de la buton are dimensiunile gresite. [[7]](#poza7)

# Poze

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

Closed 2025-04-12.

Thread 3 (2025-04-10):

[PCB & 3D model] Probleme la alinierea PCB-ul in carcasa.

Matei-Dragusin, 2025-04-10:
# Descriere
Nu au fost respectate dimensiunile date pentru asezarea slotului de card SD.

# Problema
Nu se poate introduce un card SD.

# Poze

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

Closed 2025-04-12.

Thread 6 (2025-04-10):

[Schematic] Pini suprapusi de fire

Matei-Dragusin, 2025-04-10:
# Descriere
Net PREVGH overlaps pin
Net PREVGH overlaps pin
Net 3V3 overlaps pin

# Problema
La piesele E-Paper Display Header si Reset Button, unele fire suprapun pini.

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

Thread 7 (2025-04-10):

[Schematic] Warning-uri la schematic

Matei-Dragusin, 2025-04-10:
# Descriere
22 de warninguri (3 dintre ele au deja alt issue, vezi #6).

# Poze

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

Closed 2025-04-12.

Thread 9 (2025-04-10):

[README] Readme sumar

Matei-Dragusin, 2025-04-10:
# Descriere
Readme sumar, lipsa elemente importante

# Solutie
Mentioneaza in README detalii despre procesul de gândire și alte alegeri pe care le-ai făcut.

Closed 2025-04-12.

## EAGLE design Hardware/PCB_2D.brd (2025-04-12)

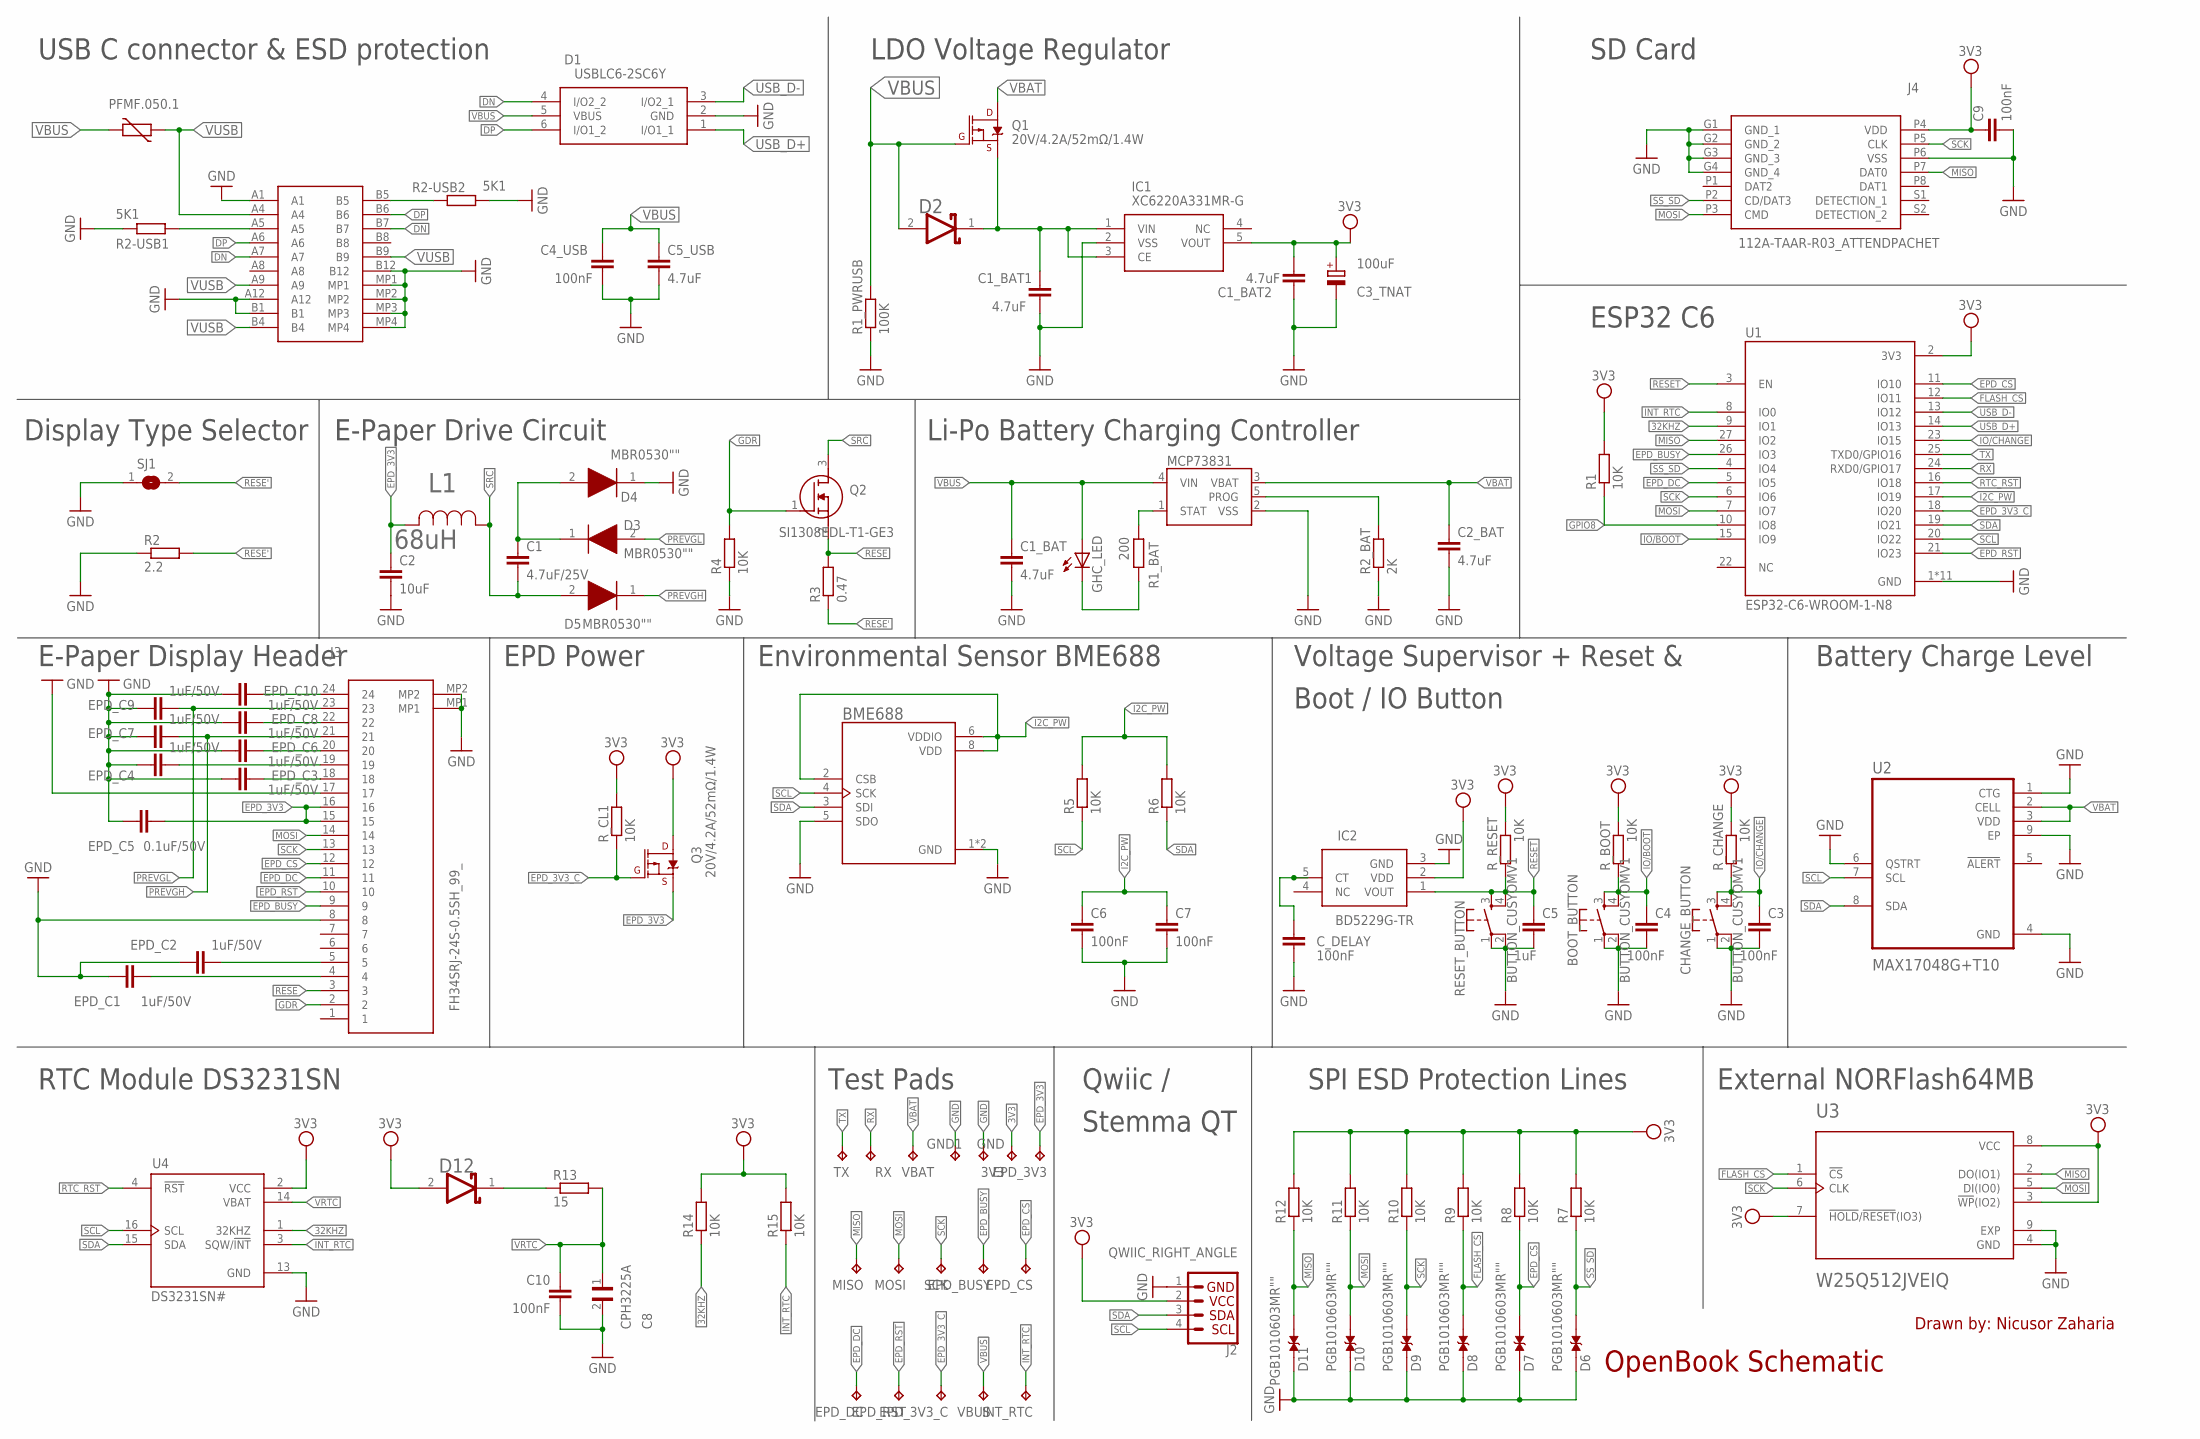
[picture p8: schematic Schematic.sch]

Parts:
3V3: TPTP20R; TP20R
BME688: ESP32_WROVER_BME680_BME680; ESP32_WROVER_BME680_PSON80P300X300X100-8N
BOOT_BUTTON: BUTTON_CUSYOMV1; MYBUTTON
C1: 4.7uF/25V; EAGLE-LTSPICE_C0402
C1_BAT, C1_BAT1, C1_BAT2, C2_BAT, C5_USB: 4.7uF; EAGLE-LTSPICE_C0402
C2: 10uF; EAGLE-LTSPICE_C0402
C3, C4, C4_USB, C6, C7, C9, C10: 100nF; EAGLE-LTSPICE_C0402
C3_TNAT: 100uF; RCL_CT3528
C5: 1uF; EAGLE-LTSPICE_C0402
C8: CPH3225A; CAPCP3225X100N
CHANGE_BUTTON: BUTTON_CUSYOMV1; MYBUTTON
C_DELAY: 100nF; EAGLE-LTSPICE_C0402
D1: USBLC6-2SC6Y; SOT95P280X145-6N
D2, D12: ESP32_WROVER_AVX---SD0805S020S1R0_AVX_SD0805S020S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; ESP32_WROVER_AVX---SD0805S020S1R0_AVX_SD0805S020S1R0_0
D3, D4, D5: MBR0530""; SOD3716X135N
D6, D7, D8, D9, D10, D11: PGB1010603MR""; DIOC1608X36N
EPD_3V3, EPD_3V3_C: TPTP20R; TP20R
EPD_BUSY: TPTP20R; TP20R
EPD_C1, EPD_C2, EPD_C3, EPD_C4, EPD_C6, EPD_C7, EPD_C8, EPD_C9, EPD_C10: 1uF/50V; EAGLE-LTSPICE_C0402
EPD_C5: 0.1uF/50V; EAGLE-LTSPICE_C0402
EPD_CS: TPTP20R; TP20R
EPD_DC: TPTP20R; TP20R
EPD_RST: TPTP20R; TP20R
GHC_LED: ADAFRUIT_LEDCHIP-LED0603; ADAFRUIT_CHIP-LED0603
GND, GND1: TPTP20R; TP20R
IC1: XC6220A331MR-G; SOT95P280X120-5N
IC2: BD5229G-TR; SOT95P280X125-5N
INT_RTC: TPTP20R; TP20R
J1: SAMACSYS_PARTS_USB4110-GF-A; SAMACSYS_PARTS_USB4110GFA
J2: QWIIC_RIGHT_ANGLE; JST04_1MM_RA
J3: FH34SRJ-24S-0.5SH_99_; FH34SRJ24S05SH99
J4: 112A-TAAR-R03_ATTENDPACHET; 112ATAARR03ATTEND
L1: 68uH; IND_4828-WE-TPC_WRE
MCP73831: ESP32_WROVER_SPARKFUN-IC-POWER_MCP73831; ESP32_WROVER_SPARKFUN-IC-POWER_SOT23-5
MISO: TPTP20R; TP20R
MOSI: TPTP20R; TP20R
PFMF.050.1: ESP32C6_VARISTORCN1812; ESP32C6_VARISTOR_CT/CN1812
Q1, Q3: 20V/4.2A/52mΩ/1.4W; ESP32_WROVER_SPARKFUN-DISCRETESEMI_SOT23-3
Q2: SI1308EDL-T1-GE3; SOT65P210X110-3N
R1, R4, R5, R6, R7, R8, R9, R10, R11, R12, R14, R15: 10K; ESP32_WROVER_EAGLE-LTSPICE_R0402
R1_BAT: 200; ESP32_WROVER_EAGLE-LTSPICE_R0402
R1_PWRUSB: 100K; ESP32_WROVER_EAGLE-LTSPICE_R0402
R2: 2.2; ESP32_WROVER_EAGLE-LTSPICE_R0402
R2-USB1, R2-USB2: 5K1; ESP32_WROVER_EAGLE-LTSPICE_R0402
R2_BAT: 2K; ESP32_WROVER_EAGLE-LTSPICE_R0402
R3: 0.47; ESP32_WROVER_EAGLE-LTSPICE_R0402
R13: 15; ESP32_WROVER_EAGLE-LTSPICE_R0402
RESET_BUTTON: BUTTON_CUSYOMV1; MYBUTTON
RX: TPTP20R; TP20R
R_BOOT: 10K; ESP32_WROVER_EAGLE-LTSPICE_R0402
R_CHANGE: 10K; ESP32_WROVER_EAGLE-LTSPICE_R0402
R_CL1: 10K; ESP32_WROVER_EAGLE-LTSPICE_R0402
R_RESET: 10K; ESP32_WROVER_EAGLE-LTSPICE_R0402
SCK: TPTP20R; TP20R
SJ1: SJ
TX: TPTP20R; TP20R
U1: ESP32-C6-WROOM-1-N8; XCVR_ESP32-C6-WROOM-1-N8
U2: MAX17048G+T10; SON50P200X200X80-9N
U3: W25Q512JVEIQ; SON127P600X800X80-9N
U4: DS3231SN#; SOIC127P1032X265-16N
VBAT: TPTP20R; TP20R
VBUS: TPTP20R; TP20R

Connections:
3V3: 3V3.TP, C1_BAT2.1, C3_TNAT.+, C9.1, D12.2 (ANODE), IC1.5 (VOUT), IC2.2 (VDD), J2.2, J4.P4 (VDD), Q3.3 (D), R1.2, R7.2, R8.2, R9.2, R10.2, R11.2, R12.2, R14.2, R15.2, R_BOOT.2, R_CHANGE.2, R_CL1.2, R_RESET.2, U1.2 (3V3), U3.3 (!WP!(IO2)), U3.7 (!HOLD!/!RESET!(IO3)), U3.8 (VCC), U4.2 (VCC)
32KHZ: R14.1, U1.9 (IO1), U4.1 (32KHZ)
DN: D1.4 (I/O2_2), J1.A7, J1.B7
DP: D1.6 (I/O1_2), J1.A6, J1.B6
EPD_3V3: C2.1, EPD_3V3.TP, EPD_C5.2, J3.15, J3.16, L1.2, Q3.2 (S)
EPD_3V3_C: EPD_3V3_C.TP, Q3.1 (G), R_CL1.1, U1.18 (IO20)
EPD_BUSY: EPD_BUSY.TP, J3.9, U1.26 (IO3)
EPD_CS: D7.2, EPD_CS.TP, J3.12, R8.1, U1.11 (IO10)
EPD_DC: EPD_DC.TP, J3.11, U1.5 (IO5)
EPD_RST: EPD_RST.TP, J3.10, U1.21 (IO23)
FLASH_CS: D8.2, R9.1, U1.12 (IO11), U3.1 (!CS)
GDR: J3.2, Q2.1 (G), R4.2
GND: BME688.1 (GND), BME688.5 (SDO), BME688.7 (GND), BOOT_BUTTON.1, BOOT_BUTTON.2, C1_BAT.2, C1_BAT1.2, C1_BAT2.2, C2.2, C2_BAT.2, C3.2, C3_TNAT.-, C4.2, C4_USB.2, C5.2, C5_USB.2, C6.2, C7.2, C8.2, C9.2, C10.2, CHANGE_BUTTON.1, CHANGE_BUTTON.2, C_DELAY.2, D1.2 (GND), D4.1 (K), D6.1, D7.1, D8.1, D9.1, D10.1, D11.1, EPD_C1.1, EPD_C2.1, EPD_C3.1, EPD_C4.1, EPD_C5.1, EPD_C6.1, EPD_C7.1, EPD_C8.1, EPD_C9.1, EPD_C10.1, GND.TP, GND1.TP, IC1.2 (VSS), IC2.3 (GND), J1.A1, J1.A12, J1.B1, J1.B12, J1.MP1, J1.MP2, J1.MP3, J1.MP4, J2.1, J3.8, J3.17, J3.MP1, J3.MP2, J4.G1 (GND_1), J4.G2 (GND_2), J4.G3 (GND_3), J4.G4 (GND_4), J4.P6 (VSS), MCP73831.2 (VSS), R1_PWRUSB.1, R2.1, R2-USB1.1, R2-USB2.2, R2_BAT.1, R4.1, RESET_BUTTON.1, RESET_BUTTON.2, SJ1.1, U1.1 (GND), U1.28 (GND), U1.29_1 (GND), U1.29_2 (GND), U1.29_3 (GND), U1.29_4 (GND), U1.29_5 (GND), U1.29_6 (GND), U1.29_7 (GND), U1.29_8 (GND), U1.29_9 (GND), U2.1 (CTG), U2.4 (GND), U2.6 (QSTRT), U2.9 (EP), U3.4 (GND), U3.9 (EXP), U4.13 (GND)
GPIO8: R1.1, U1.10 (IO8)
I2C_PW: BME688.2 (CSB), BME688.6 (VDDIO), BME688.8 (VDD), C6.1, C7.1, R5.2, R6.2, U1.17 (IO19)
INT_RTC: INT_RTC.TP, R15.1, U1.8 (IO0), U4.3 (SQW/!INT)
IO/BOOT: BOOT_BUTTON.3, BOOT_BUTTON.4, C4.1, R_BOOT.1, U1.15 (IO9)
IO/CHANGE: C3.1, CHANGE_BUTTON.3, CHANGE_BUTTON.4, R_CHANGE.1, U1.23 (IO15)
MISO: D11.2, J4.P7 (DAT0), MISO.TP, R12.1, U1.27 (IO2), U3.2 (DO(IO1))
MOSI: D10.2, J3.14, J4.P3 (CMD), MOSI.TP, R11.1, U1.7 (IO7), U3.5 (DI(IO0))
unnamed: J1.A5, R2-USB1.2
unnamed: J1.B5, R2-USB2.1
unnamed: C1_BAT1.1, D2.1 (CATHODE), IC1.1 (VIN), IC1.3 (CE), Q1.2 (S)
unnamed: MCP73831.1 (STAT), R1_BAT.2
unnamed: MCP73831.5 (PROG), R2_BAT.2
unnamed: GHC_LED.C, R1_BAT.1
unnamed: C_DELAY.1, IC2.5 (CT)
unnamed: EPD_C3.2, J3.18
unnamed: C1.1, D3.1 (K), D4.2 (A)
unnamed: EPD_C6.2, J3.20
unnamed: EPD_C1.2, J3.4
unnamed: D12.1 (CATHODE), R13.1
unnamed: EPD_C2.2, J3.5
unnamed: EPD_C8.2, J3.22
unnamed: EPD_C10.2, J3.24
unnamed: EPD_C4.2, J3.19
PREVGH: D5.1 (K), EPD_C7.2, J3.21
PREVGL: D3.2 (A), EPD_C9.2, J3.23
RESE: J3.3, Q2.2 (S), R3.2
RESE': R2.2, R3.1, SJ1.2
RESET: C5.1, IC2.1 (VOUT), RESET_BUTTON.3, RESET_BUTTON.4, R_RESET.1, U1.3 (EN)
RTC_RST: U1.16 (IO18), U4.4 (!RST)
RX: RX.TP, U1.24 (RXD0/GPIO17)
SCK: D9.2, J3.13, J4.P5 (CLK), R10.1, SCK.TP, U1.6 (IO6), U3.6 (CLK)
SCL: BME688.4 (SCK), J2.4, R5.1, U1.20 (IO22), U2.7 (SCL), U4.16 (SCL)
SDA: BME688.3 (SDI), J2.3, R6.1, U1.19 (IO21), U2.8 (SDA), U4.15 (SDA)
SRC: C1.2, D5.2 (A), L1.1, Q2.3 (D)
SS_SD: D6.2, J4.P2 (CD/DAT3), R7.1, U1.4 (IO4)
TX: TX.TP, U1.25 (TXD0/GPIO16)
USB_D+: D1.1 (I/O1_1), U1.14 (IO13)
USB_D-: D1.3 (I/O2_1), U1.13 (IO12)
VBAT: C2_BAT.1, MCP73831.3 (VBAT), Q1.3 (D), U2.2 (CELL), U2.3 (VDD), VBAT.TP
VBUS: C1_BAT.1, C4_USB.1, C5_USB.1, D1.5 (VBUS), D2.2 (ANODE), GHC_LED.A, MCP73831.4 (VIN), PFMF.050.1.2, Q1.1 (G), R1_PWRUSB.2, VBUS.TP
VRTC: C8.1, C10.1, R13.2, U4.14 (VBAT)
VUSB: J1.A4, J1.A9, J1.B4, J1.B9, PFMF.050.1.1

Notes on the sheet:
USB C connector & ESD protection
LDO Voltage Regulator
SD Card
ESP32 C6
Li-Po Battery Charging Controller
E-Paper Drive Circuit
Display Type Selector
Battery Charge Level
Voltage Supervisor + Reset &
Boot / IO Button
Environmental Sensor BME688
EPD Power
E-Paper Display Header
External NORFlash64MB
SPI ESD Protection Lines
Qwiic /
Stemma QT
Test Pads
RTC Module DS3231SN
Drawn by: Nicusor Zaharia
OpenBook Schematic

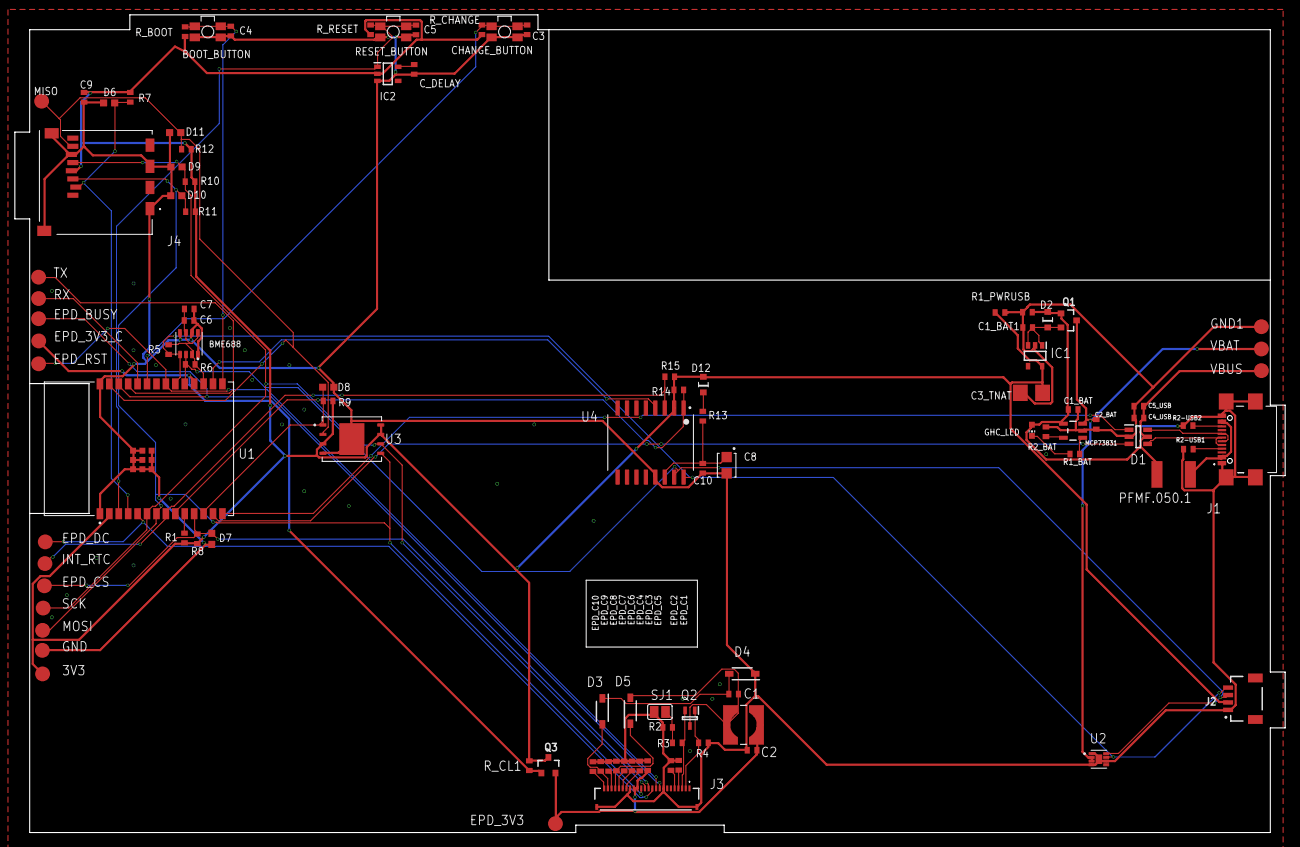
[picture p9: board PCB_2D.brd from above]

Board: 2 copper layers, 171.2 x 110.2 mm, 103 parts (0 on the bottom side), 55 nets.

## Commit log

2025-04-06 Add Schematic and 2D PCB files
    [PCB_2D.brd, Schematic.sch]
2025-04-06 Add manufacturing files
    Added gerbers, bill of materials and Pick and Place file
    [Bill of materials.csv, Pick and Place.csv]
2025-04-12 Fixes #1. #2. #3. #4. #5. #6. #7 #8 #9: Improved 3D models, silkscreen and schematic
    [PCB_2D.brd, Schematic.sch]

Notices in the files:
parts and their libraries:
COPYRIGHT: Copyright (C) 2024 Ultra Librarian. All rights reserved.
